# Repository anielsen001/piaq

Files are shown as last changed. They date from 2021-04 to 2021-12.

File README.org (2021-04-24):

#+TITLE: Raspbery Pi zero based air quality sensor.

Very much a work in progress. 

I wanted a flexible framework to monitor air quality, so I used a Raspberry Pi Zero-W mated to air quality breakouts from Adafruit. 

Currently logs data to csv file on the sd-card. 

Records carbon dioxide, PM2.5, VOCs

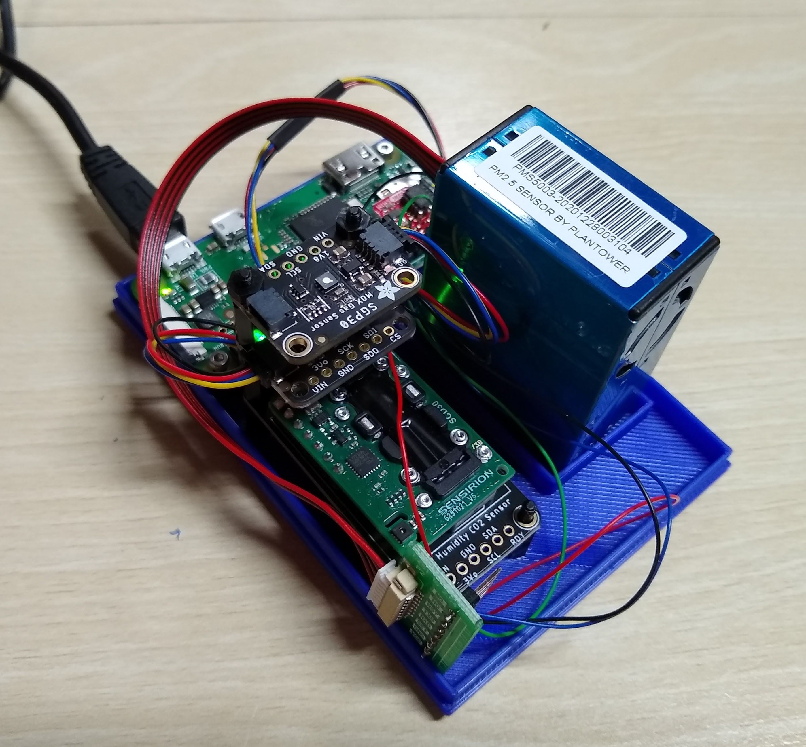
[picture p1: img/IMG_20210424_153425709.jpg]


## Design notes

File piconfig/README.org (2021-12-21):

#+TITLE: Raspberry Pi 0 W Configuration

* Turn off the Pi's LED

Add the following line to the crontab
#+begin_src
@reboot echo 0 | sudo tee /sys/class/leds/led0/brightness
#+end_src

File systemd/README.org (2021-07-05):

#+TITLE: running at startup

The logger can be set to run at system startup using systemd. This directory has a service file for the piaq service. Link this file into the systemd directory. There is also a separate flask web service that will show the current readings.

#+begin_src 
sudo ln -s $PWD/piaq.service /lib/systemd/system/piaq.service
sudo ln -s $PWD/web.service /lib/systemd/system/web.service
#+end_src

Then enable the service on startup

#+begin_src
sudo systemctl daemon-reload
sudo systemctl enable piaq.service
sudo systemctl enable web.service
#+end_src

* References

https://www.dexterindustries.com/howto/run-a-program-on-your-raspberry-pi-at-startup/

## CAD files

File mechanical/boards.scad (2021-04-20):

pi_pcb_thick = 1.6; 
pi_x = 65.0; 
pi_y = 30.0; 
pi_thru_hole_offset = 3.5; 

pm25_x = 21.5; 
pm25_y = 38.25;
pm25_z = 51.1; 

inch2mm = 25.4;

/* 
 * define pi zero dims 
   https://www.raspberrypi.org/documentation/hardware/raspberrypi/mechanical/README.md   
   holes are for M2.5
 * 
 */
module board_pi_zero_w(){
    x = pi_x; 
    y = pi_y;
    z = pi_pcb_thick;  // pcb thickness
    
    
    difference() {
    color("green") cube([x,y,z]); // primary board
    pi_zero_thru_holes(x,y,z);
    }
    board_pi_zero_sdcard();
    board_pi_zero_usb_pwr();
}

module pi_zero_thru_holes(x,y,z){
    
        thru_hole_diam = 2.5; 
        thru_hole_offset = pi_thru_hole_offset; // all hole centers are 3.5 mm from edges in both directions

        translate([thru_hole_offset, thru_hole_offset,0])
            cylinder(r=thru_hole_diam/2,h=10,$fn=16);
        translate([x-thru_hole_offset, thru_hole_offset,0])
            cylinder(r=thru_hole_diam/2,h=10,$fn=16);
        translate([thru_hole_offset, y-thru_hole_offset,0])
            cylinder(r=thru_hole_diam/2,h=10,$fn=16);
        translate([x-thru_hole_offset, y-thru_hole_offset,0])
            cylinder(r=thru_hole_diam/2,h=10,$fn=16);
}

module board_pi_zero_sdcard(){
    
    //pi_pcb_thick=1.6; 
    sd_card_center_offset=16.9;
    sd_card_x = 12.4;
    sd_card_y = 12.4; 
    sd_card_thick = 3;
    translate([0,sd_card_center_offset-sd_card_y/2,pi_pcb_thick])
        cube([sd_card_x,sd_card_y,sd_card_thick]);
}

module board_pi_zero_usb_pwr(){
    usb_offset = 54;
    usb_width = 8.2;
    usb_thick = 3.25; 
    //pi_pcb_thick=1.6; 
    translate([usb_offset-usb_width/2,0,pi_pcb_thick])
        cube([usb_width,usb_width,usb_thick]);
    
}

/* this is the CO2 sensor SDC30
 * other boards stack on it
 * https://learn.adafruit.com/adafruit-scd30/downloads
 */
module SCD30_board(){
    // original dimensions in inches
    x = 2.0*inch2mm;
    y = 1.0*inch2mm;
    z = 2.0; // mm not too critical
    
    // hole offsets are the same from each corner
    thru_hole_offset =  (1.0-0.8)/2 * inch2mm;
    thru_hole_diam = 2.5; 
    
    difference(){
        color("blue") cube([x,y,z]);
        translate([thru_hole_offset, thru_hole_offset,0])
            cylinder(r=thru_hole_diam/2,h=10,$fn=16);
        translate([x-thru_hole_offset, thru_hole_offset,0])
            cylinder(r=thru_hole_diam/2,h=10,$fn=16);
        translate([thru_hole_offset, y-thru_hole_offset,0])
            cylinder(r=thru_hole_diam/2,h=10,$fn=16);
        translate([x-thru_hole_offset, y-thru_hole_offset,0])
            cylinder(r=thru_hole_diam/2,h=10,$fn=16);
    }
}

/* this is the Plantower 2.5 particulate matter sensor
*/  
module plantower_pm25(){
    x = pm25_x;
    y = pm25_y;
    z = pm25_z;
    color("blue") cube([x,y,z]);
}

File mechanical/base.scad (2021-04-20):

// include the external boards for reference
include <boards.scad>;

//pm25_offset_x = 32;
//pm25_offset_y = 40;
//pm25_rotate = 90;

pm25_offset_x = 0;
pm25_offset_y = 40;
pm25_rotate = 0;

pi_standoff_height=5.0;
pi_standoff_diam=5;

// basic base
module base(){
    x = 70; 
    y = 100; 
    z = 3;
    
    difference(){
    translate([-2.5,-2.5,-z])cube([x,y,z]);
    
    // add holes for SDC30 standoffs - 
    thru_hole_offset =  (1.0-0.8)/2 * inch2mm;
    thru_hole_diam = 2.5; 
    translate([63,35,-10])rotate([0,0,90])
        union(){
            x=2.0*inch2mm;
            y=1.0*inch2mm;
            z=-10.0;
    translate([thru_hole_offset, thru_hole_offset,0])
        cylinder(r=thru_hole_diam/2,h=200,$fn=16);
    translate([x-thru_hole_offset, thru_hole_offset,0])
        cylinder(r=thru_hole_diam/2,h=200,$fn=16);
    translate([thru_hole_offset, y-thru_hole_offset,0])
        cylinder(r=thru_hole_diam/2,h=200,$fn=16);
    translate([x-thru_hole_offset, y-thru_hole_offset,0])
        cylinder(r=thru_hole_diam/2,h=200,$fn=16);
        } //end union
    //} //end difference
           
       // this makes the pi mounting  holes thru holes 
       color("blue")      union(){
            standoff_hole_diam=2.0;
            translate([pi_thru_hole_offset, pi_thru_hole_offset,-100]) cylinder(r=standoff_hole_diam/2,h=200,$fn=16);
            translate([pi_x-pi_thru_hole_offset, pi_thru_hole_offset,-100])            cylinder(r=standoff_hole_diam/2,h=200,$fn=16);
            translate([pi_thru_hole_offset, pi_y-pi_thru_hole_offset,-100])            cylinder(r=standoff_hole_diam/2,h=200,$fn=16);
            translate([pi_x-pi_thru_hole_offset, pi_y-pi_thru_hole_offset,-100])           cylinder(r=standoff_hole_diam/2,h=200,$fn=16);
        }//end union       
        
            
    } //end difference
        
        
    // the base needs a slot to hold the pm2.5 sensor
    // dimensions loaded from include file
    slot_height=5.0;
    slot_width=5;
    slot_wall_thick=2.0;
    translate([pm25_offset_x+slot_width/2,pm25_offset_y-slot_width/2,0]) rotate([0,0,pm25_rotate])
    difference(){
    cube([pm25_x+slot_width,pm25_y+slot_width,slot_height]);
        translate([slot_wall_thick/2,slot_wall_thick/2,0])
        cube([pm25_x+slot_width-slot_wall_thick,pm25_y+slot_width-slot_wall_thick,slot_height]);
    }
    
    // create standoffs for the raspberry pi
    difference(){
        union(){
            translate([pi_thru_hole_offset,      pi_thru_hole_offset,0]) cylinder(r=pi_standoff_diam/2,h=pi_standoff_height,$fn=16);
            translate([pi_x-pi_thru_hole_offset, pi_thru_hole_offset,0]) cylinder(r=pi_standoff_diam/2,h=pi_standoff_height,$fn=16);
            translate([pi_thru_hole_offset,      pi_y-pi_thru_hole_offset,0]) cylinder(r=pi_standoff_diam/2,h=pi_standoff_height,$fn=16);
            translate([pi_x-pi_thru_hole_offset, pi_y-pi_thru_hole_offset,0]) cylinder(r=pi_standoff_diam/2,h=pi_standoff_height,$fn=16);
        }//end union
        union(){
            standoff_hole_diam=2.0;
            translate([pi_thru_hole_offset, pi_thru_hole_offset,0])
                cylinder(r=standoff_hole_diam/2,h=pi_standoff_height,$fn=16);
            translate([pi_x-pi_thru_hole_offset, pi_thru_hole_offset,0])            cylinder(r=standoff_hole_diam/2,h=pi_standoff_height,$fn=16);
            translate([pi_thru_hole_offset, pi_y-pi_thru_hole_offset,0])            cylinder(r=standoff_hole_diam/2,h=pi_standoff_height,$fn=16);
            translate([pi_x-pi_thru_hole_offset, pi_y-pi_thru_hole_offset,0])           cylinder(r=standoff_hole_diam/2,h=pi_standoff_height,$fn=16);
        }//end union
    
    }//end  difference   
    
    // add edge rim to hold top in place
    edge_rim_thick = 2.0;
    edge_rim_gap = 1.0;
    edge_rim_height = 5.0;
    translate([-2.5,-2.5,0])
    translate([edge_rim_gap,edge_rim_gap,0])
    
    difference(){
        cube([x-edge_rim_gap*2,y-edge_rim_gap*2,edge_rim_height]);
        translate([edge_rim_gap,edge_rim_gap,0])cube([x-edge_rim_gap*2-edge_rim_thick,y-edge_rim_gap*2-edge_rim_thick,edge_rim_height]);  
    }
    

}



//translate([0,0,pi_standoff_height])board_pi_zero_w();
//translate([63,35,0])rotate([0,0,90]) SCD30_board();
//translate([pm25_offset_x,pm25_offset_y,0]) rotate([0,0,pm25_rotate]) plantower_pm25();

base();

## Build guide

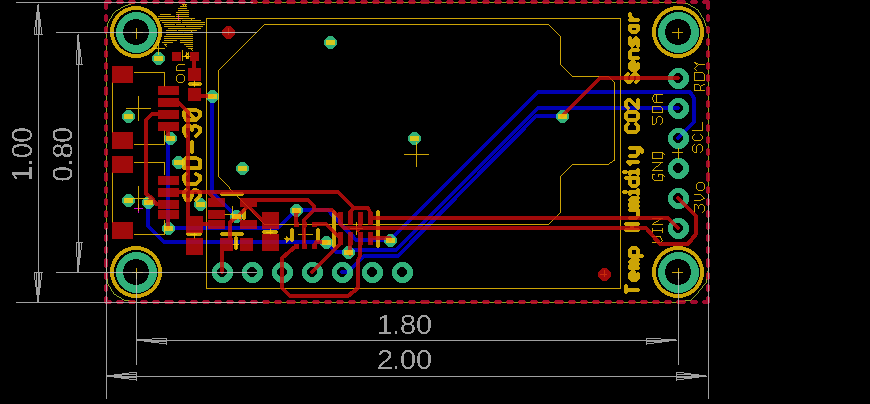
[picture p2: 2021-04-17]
docs/adafruit_products_SCD30_fab_print.png

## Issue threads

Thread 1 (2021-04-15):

create unique log file name on each start

anielsen001, 2021-04-15:
current code just uses the name log.csv and overwrites the existing file. The code should create a name based on the date and time to make it clear when the file was created and keep it unique.

anielsen001, 2021-06-14:
Switched to using leg gong Module with Time Rotator.currently now legsare created at
Midnight

Closed 2021-12-16.

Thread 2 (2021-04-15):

break pm25 read into separate module to make exception handling easier

anielsen001, 2021-04-15:
The uart interface is prone to issues and breaking the pm25 read out to make handling those exceptions easier would be preferrerd.

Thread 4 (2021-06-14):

Add E- ink display

anielsen001, 2021-06-14:
show current status and info.

anielsen001, 2021-06-14:
https://learn.adafruit.com/adafruit-eink-display-breakouts/pinouts

https://pinout.xyz/

anielsen001, 2021-06-14:
https://learn.adafruit.com/raspberry-pi-e-ink-weather-station-using-python/weather-station-code
https://cdn-learn.adafruit.com/assets/assets/000/093/100/original/raspberry_pi_breakout_bb.jpg?1594686262

anielsen001, 2021-06-18:
Pinouts https://learn.adafruit.com/assets/93100

anielsen001, 2021-06-18:
sudo apt-get install libtiff5 libopenjp2-7-dev

Closed 2021-07-05.

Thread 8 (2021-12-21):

turn off pi led light

anielsen001, 2021-12-21:

anielsen001, 2021-12-21:
Add to crontab
```
@reboot echo 0 | sudo tee /sys/class/leds/led0/brightness
```
and update documentation.

Closed 2021-12-21.

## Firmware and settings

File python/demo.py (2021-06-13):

import logging
from logging.handlers import TimedRotatingFileHandler

import datetime
import time
import board
 
# import digitalio # For use with SPI
import busio
import adafruit_bmp280
import adafruit_sgp30
import adafruit_scd30

DEBUG=False

if DEBUG:
    my_log_level = logging.DEBUG
else:
    my_log_level = logging.INFO

# create logger for data
datalogger = logging.getLogger('data logger')
datalogger.setLevel(my_log_level)

# create a file handler
fh = TimedRotatingFileHandler("/home/pi/log",when="midnight")
fh.suffix = '%Y-%m-%d_%H-%M-%S.csv'
fh.setLevel(logging.INFO)
# create a formatter
frmt = logging.Formatter('%(message)s') # show only message
fh.setFormatter(frmt)

# add the handler to the logger
datalogger.addHandler(fh)

# create a screen handling for display in case of debugging
if DEBUG:
    sh = logging.StreamHandler()
    sh.setLevel(my_log_level)
    sh.setFormatter(frmt)
    datalogger.addHandler(sh)

# for pm2.5 sensor
import serial
uart = serial.Serial("/dev/ttyS0", baudrate=9600, timeout=0.25)
from adafruit_pm25.uart import PM25_UART
reset_pin = None
pm25 = PM25_UART(uart, reset_pin)

SAMPLE_PERIOD=10.0 # seconds
 
# Create library object using our Bus I2C port
i2c = busio.I2C(board.SCL, board.SDA)

sgp30 = adafruit_sgp30.Adafruit_SGP30(i2c)
bmp280 = adafruit_bmp280.Adafruit_BMP280_I2C(i2c)
scd = adafruit_scd30.SCD30(i2c)
 
# change this to match the location's pressure (hPa) at sea level
bmp280.sea_level_pressure = 1013.25

# must do these first to initialize the sensor
sgp30.iaq_init()
sgp30.set_iaq_baseline(0x8973, 0x8AAE)
 
# write a header into the log file
msgparts = ['# datetime',
            'eC02',
            'TVOC',
            'PM10',
            'PM25',
            'PM100',
            'SCD30_CO2',
            'SCD30_Temp',
            'SCD30_RH',
            'BMP280_Temp',
            'BMP280_Pres',
            'BMP280_Alt']
datalogger.debug(','.join(msgparts))

# sleep before starting to settle
time.sleep(1)

#with open(logfile,'a') as f:
while True:

    try:
        pm25data= pm25.read()

        msgparts = [str(datetime.datetime.now()),
                    str(sgp30.eCO2),
                    str(sgp30.TVOC),
                    str(pm25data["pm10 standard"]),
                    str(pm25data["pm25 standard"]),
                    str(pm25data["pm100 standard"]),
                    str(scd.CO2),
                    str(scd.temperature),
                    str(scd.relative_humidity),
                    str(bmp280.temperature),
                    str(bmp280.pressure),
                    str(bmp280.altitude) ]
        datalogger.info(','.join(msgparts))
    except RuntimeError:
        # this occured when an invalid checksum was received from the PM2.5 sensor
        # we just skip the error and keep going
        pass
    except OSError:
        # this occured when the PM2.5 was not ready 
        # if we get an os error, just skip
        pass

    time.sleep(SAMPLE_PERIOD)

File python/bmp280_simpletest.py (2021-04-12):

# SPDX-FileCopyrightText: 2021 ladyada for Adafruit Industries
# SPDX-License-Identifier: MIT
 
"""Simpletest Example that shows how to get temperature,
   pressure, and altitude readings from a BMP280"""
import time
import board
 
# import digitalio # For use with SPI
import busio
import adafruit_bmp280
 
# Create library object using our Bus I2C port
i2c = busio.I2C(board.SCL, board.SDA)
bmp280 = adafruit_bmp280.Adafruit_BMP280_I2C(i2c)
 
# OR create library object using our Bus SPI port
# spi = busio.SPI(board.SCK, board.MOSI, board.MISO)
# bmp_cs = digitalio.DigitalInOut(board.D10)
# bmp280 = adafruit_bmp280.Adafruit_BMP280_SPI(spi, bmp_cs)
 
# change this to match the location's pressure (hPa) at sea level
bmp280.sea_level_pressure = 1013.25
 
while True:
    print("\nTemperature: %0.1f C" % bmp280.temperature)
    print("Pressure: %0.1f hPa" % bmp280.pressure)
    print("Altitude = %0.2f meters" % bmp280.altitude)
    time.sleep(2)

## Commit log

2021-04-15 added an exception check for a checksum error from the pm25 sensor
    [demo.py]
2021-04-17 added initial boards for box design
    [boards.scad]
2021-04-18 added plattower pm2.5 sensor
    [boards.scad]
2021-04-18 added base
    [base.scad]
2021-04-18 updated boards
    [boards.scad]
2021-04-19 initial base design complete
    [base.scad]
2021-04-20 updated dimensions and thru hole positions
    [base.scad, boards.scad]
2021-04-26 removed print to screen
2021-04-26 changed logfile to append mode, changed file locations to full path specification and removed print to screen
2021-06-13 added manual for plantower particle sensor
2021-06-13 made the sample period reconfigurable
2021-06-13 switch to using logger
2021-12-16 added simple current status api
